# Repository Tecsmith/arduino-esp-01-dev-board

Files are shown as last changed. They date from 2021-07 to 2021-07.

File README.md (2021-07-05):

# Development board for ESP-01

| Board | URL |
|---|---|
| [ESP-01 Qwiic Development Board](https://tecsmith.github.io/arduino-esp-01-dev-board/) | [`c1k.it/esp1`](http://c1k.it/esp1) |

## Help, About, *etc.*

Refer to the [docs folder](docs/index.md).

<p align="center" style="color:#069">★</p>

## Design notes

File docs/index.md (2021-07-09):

# ESP-01 Qwiic Development Board

An ESP-01 Development Board with power, programming and Qwiic headers

GitHub repository at [Tecsmith/arduino-esp-01-dev-board](https://github.com/Tecsmith/arduino-esp-01-dev-board/)

----------

## Features & Specifications

- Host of ESP-01 (or ESP-01S) module.
- Powered from USB Micro-B connector
- Serial programing breakout pins (for use with SparkFun [FTDI 3.3V Breakout](https://www.sparkfun.com/products/9873))
- I<sup>2</sup>C breakout pins (SCL, SDA, 3V3, GND)
- Qwiic connector (works with SparkFun's [Qwiic Connect System](https://www.sparkfun.com/qwiic))
- Tactile GPIO0 momentary button (press to set ESP8266 into programming mode while booting)
- Tactile RESET momentary button (press to reboot ESP8266)
- Unlike common designs, this uses GPIO-0/GPIO-2 for I<sup>2</sup>C, leaving TX/RX (GPIO-1/GPIO-3) available for serial debug.

----------

## ESP-01 Pinout

| DevBrd | ESP |  Pin  |  Pin  | ESP | DevBrd |
|---:|---:|:-----:|:-----:|:---|:---|
| RXI / RXD | GPIO-3 / RX | **5** | **4** | VCC (3.3V)  | 3V3 |
| SCL / [*Prog/IO0*] | GPIO-0 | **6** | **3** | RST | [*Reset*] |
| SDA | GPIO-2 | **7** | **2** | CH_PD / EN  | EN / Enable |
| GND | GND | **8** | **1** | GPIO-1 / TX | TXO / TXD |

#### Sequence for placing EPS-01 in programing mode

1. Press and hold [*Reset*] button.
2. Press and hold [*Prog/IO0*] button.
3. Release [*Reset*] button
4. Wait 1 sec.
5. Pelease [*Prog/IO0*] - EPS-01 is now in "boot loader" mode.
6. *Perform upload code tasks*
7. Press and release [*Reset*] button to revert to run mode.

----------

## On Board Jumpers

### JP0 - On-board Enable
- Connected: Vcc *(3v3)* is bound to ESP-01 EN *(Enable)*
- Cut: EN is not connected, must bind EN pin to Vcc to Enable *(useful for adding on/off switch)*

### JP1 - I<sup>2</sup>C Pull Ups
- Connected _(default)_: 4.7KΩ pullups
- Cut both sides: No pullups

### JP2 - LED

As seen from the bottom:

- Tied to right (pin 2-3): LED ground to GND, always ON to show power state _(Default)_
- Tied to left (pin 1-2): LED ground to GPIO2 (as ESP-01 does) to show GPIO2 state when pulled low.
- Both cut: LED disabled

----------

## Manufacturing

* Schematic print: [esp-01-qwiic-devbrd-v1.2.pdf](esp-01-qwiic-devbrd-v1.2.pdf)
* Schematic source (in EAGLE): [Tecsmith/arduino-esp-01-dev-board/EAGLE/esp-01-qwiic-devbrd-v1.2.sch](https://github.com/Tecsmith/arduino-esp-01-dev-board/blob/main/EAGLE/esp-01-qwiic-devbrd-v1.2.sch)
* PCB design (in EAGLE): [Tecsmith/arduino-esp-01-dev-board/EAGLE/esp-01-qwiic-devbrd-v1.2.brd](https://github.com/Tecsmith/arduino-esp-01-dev-board/blob/main/EAGLE/esp-01-qwiic-devbrd-v1.2.brd)

| Top | Bottom |
|:---:|:---:|
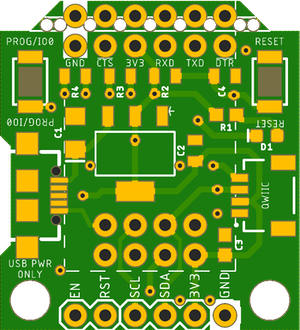
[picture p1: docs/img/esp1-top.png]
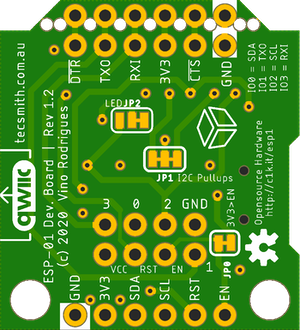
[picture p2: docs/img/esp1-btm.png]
|  |  |

<p align="center">2<sup>nd</sup> prototype built by JCLPCB</p>

----------

## Source Code

No source code is provided for the ESP-01, this is just a break out board that allows the ESP-01 to be used easily in a development environment and in some production cases.

I myself have been using [arendst/Tasmota](https://github.com/arendst/tasmota/) for MQTT integration, but the I2C on this board does ***not*** work on Tasmota base code.

Its important to note that most base code for the ESP8266 uses GPIOs 4 and 5 for I2C (as these are the manufacturers default), but the the ESP-01 board does not expose IOs 4 and 5.  This project uses GPIOs 0 and 2 for I2C (0 = SDA, 2 = SCL) and the Wire library needs to be initialised with the following code:

```cpp
// in header
#define SDA_PIN 0
#define SCL_PIN 2

// in setup()
Wire.begin(SDA_PIN, SCL_PIN);
```

----------
<p align="center" style="color:#069">&#9733;</p>

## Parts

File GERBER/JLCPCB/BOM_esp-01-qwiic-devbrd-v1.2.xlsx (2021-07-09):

Comment | Designator | Footprint | LCSC Part # (optional) | LCSC Type | Farnell Part #
TACTILE SWITCH | S1, S2 | SKRKAEE020 | C115357 | Extended | ✓
10uF Polar | C1 | CASE-A_3216 | C7171 | Basic | ✓
22uF | C2 | 805 | C45783 | Basic | ✓
0.1uF | C3 | 805 | C49678 | Basic | ✓
10uF | C4 | 805 | C15850 | Basic | ✓
1k Ohm | R1 | 805 | C17513 | Basic | ✓
4.7K Ohm | R2, R3, R4 | 805 | C17673 | Basic | ✓
BLUE | D1 | LED_0805 | C2293 | Basic | ✓
REG1117-3.3 | U2 | SOT-223 | C6186 | Basic | ✓

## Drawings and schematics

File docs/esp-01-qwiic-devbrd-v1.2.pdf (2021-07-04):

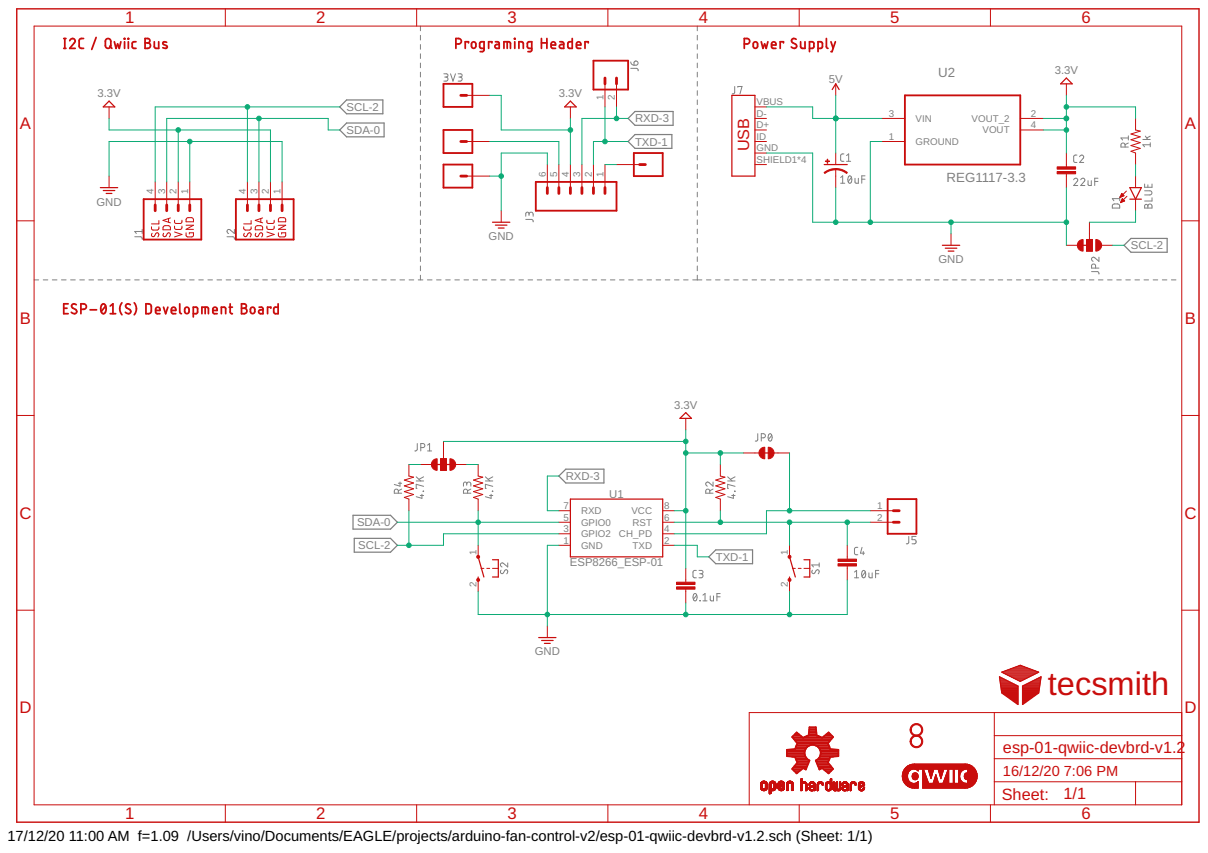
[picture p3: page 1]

17/12/20 11:00 AM f=1.09 /Users/vino/Documents/EAGLE/projects/arduino-fan-control-v2/esp-01-qwiic-devbrd-v1.2.sch (Sheet: 1/1)

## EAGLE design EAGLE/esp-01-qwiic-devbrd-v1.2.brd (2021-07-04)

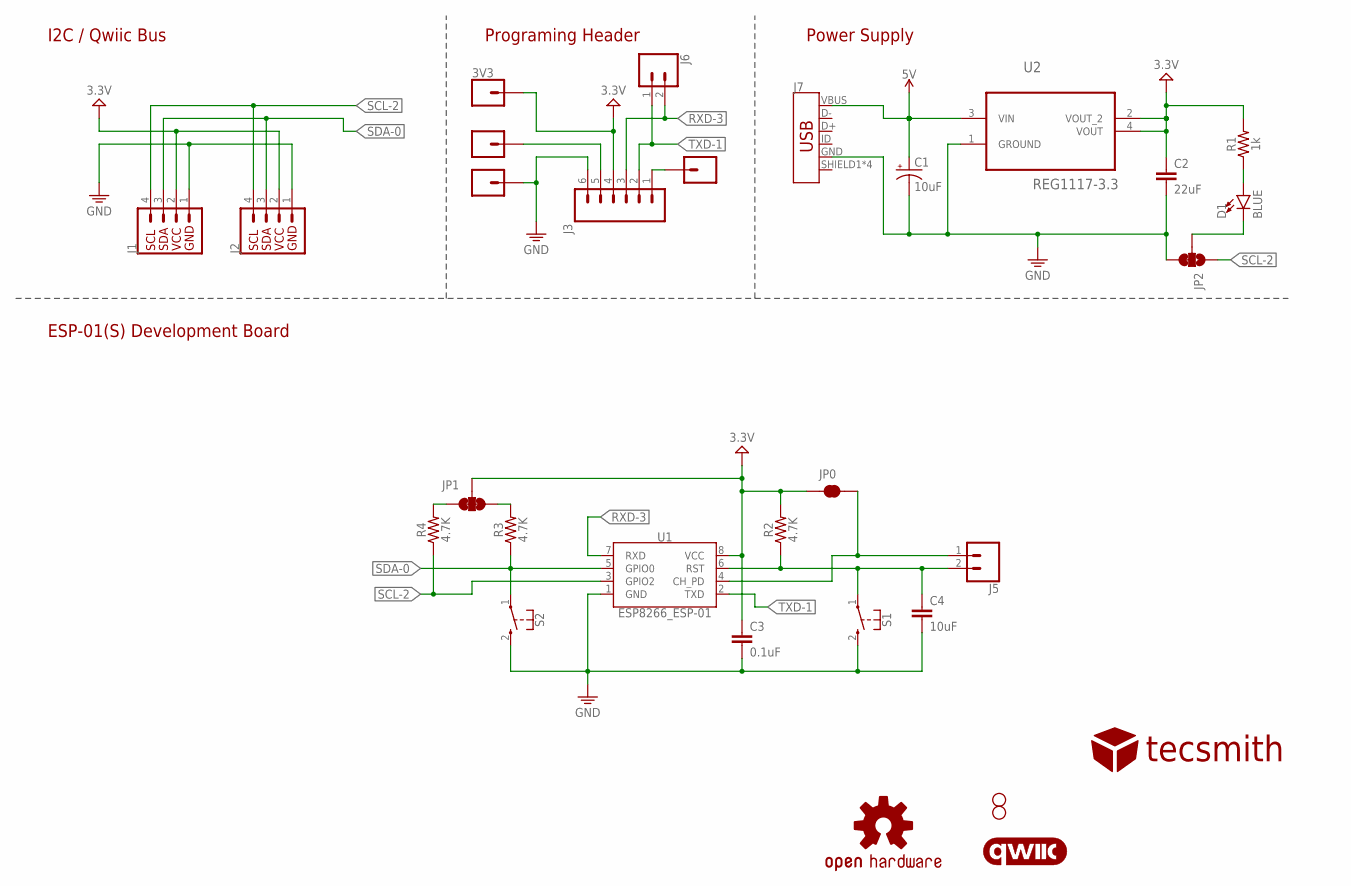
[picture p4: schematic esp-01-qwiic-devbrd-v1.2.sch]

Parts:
3V3: CONN_01PTH_NO_SILK_YES_STOP; 1X01_NO_SILK
C1: 10uF; EIA3216
C2: 22uF; 0805
C3: 0.1uF; 0603
C4: 10uF; 0805
D1: BLUE; LED-0603
H1, H2: STAND-OFF
J1: QWIIC_RIGHT_ANGLE; JST04_1MM_RA
J2: I2C_STANDARD; 1X04
J3: CONN_06NO_SILK_FEMALE_PTH; 1X06_NO_SILK
J4, J8, J9: CONN_01PTH_NO_SILK_YES_STOP; 1X01_NO_SILK
J5: CONN_02; 1X02
J6: CONN_021X02_NO_SILK; 1X02_NO_SILK
J7: USB_MICRO-B_FEMALE-SMT; USB-B-MICRO-SMD
JP0: JUMPER-SMT_2_NC_TRACE_SILK; SMT-JUMPER_2_NC_TRACE_SILK
JP1: JUMPER-SMT_3_2-NC_TRACE_SILK; SMT-JUMPER_3_2-NC_TRACE_SILK
JP2: JUMPER-SMT_3_1-NC_TRACE_SILK; SMT-JUMPER_3_1-NC_TRACE_SILK
LOGO1: OSHW-LOGOS; OSHW-LOGO-S
LOGO2: QWIIC_LOGO_6MM; QWIIC_6MM
R1: 1k; 0603
R2, R3, R4: 4.7K; 0805
S1, S2: MOMENTARY-SWITCH-SPST-1; SKRKAEE020
U1: ESP8266_ESP-01
U2: REG1117-3.3; SOT230P700X180-4N
U$1: TECSMITH-LOGO

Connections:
5V: C1.+, J7.VBUS, U2.3 (VIN)
CTS: J3.5, J8.1
DTR: J3.1, J9.1
EN: J5.1, JP0.2, U1.4 (CH_PD)
GND: C1.-, C2.2, C3.2, C4.2, J1.1, J2.1, J3.6, J4.1, J7.GND, JP2.3, S1.2 (3), S2.2 (3), U1.1 (GND), U2.1 (GROUND)
unnamed: D1.C, JP2.2
unnamed: D1.A, R1.1
unnamed: JP1.3, R4.2
unnamed: JP1.1, R3.2
RST: C4.1, J5.2, R2.1, S1.1, U1.6 (RST)
RXD-3: J3.3, J6.2, U1.7 (RXD)
SCL-2: J1.4, J2.4, JP2.1, R4.1, U1.3 (GPIO2)
SDA-0: J1.3, J2.3, R3.1, S2.1, U1.5 (GPIO0)
TXD-1: J3.2, J6.1, U1.2 (TXD)
VCC: 3V3.1, C2.1, C3.1, J1.2, J2.2, J3.4, JP0.1, JP1.2, R1.2, R2.2, U1.8 (VCC), U2.2 (VOUT_2), U2.4 (VOUT)

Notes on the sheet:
I2C / Qwiic Bus
Programing Header
Power Supply
ESP-01(S) Development Board

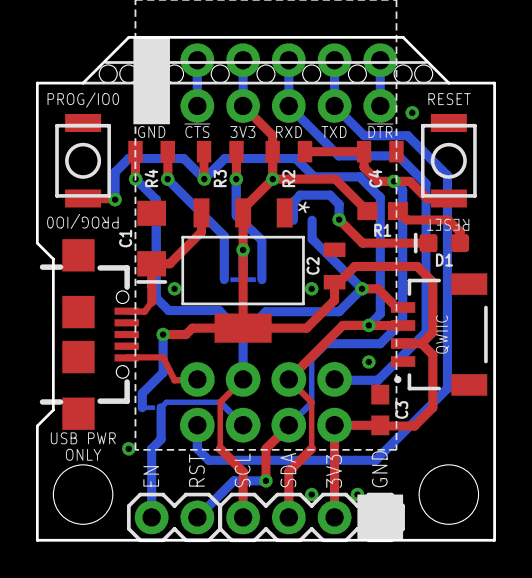
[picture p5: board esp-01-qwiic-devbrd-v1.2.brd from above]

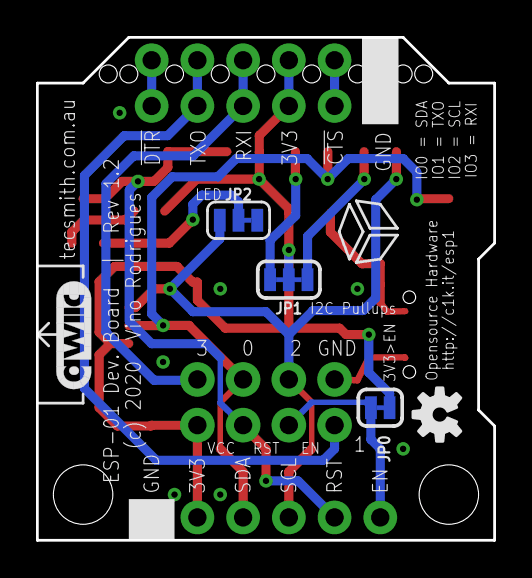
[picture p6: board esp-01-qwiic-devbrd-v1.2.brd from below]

Board: 2 copper layers, 25.4 x 27.9 mm, 31 parts (6 on the bottom side), 15 nets.

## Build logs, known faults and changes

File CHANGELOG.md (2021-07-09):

# Changelog

All notable changes to this project will be documented in this file.

The format is based on [Keep a Changelog](https://keepachangelog.com/en/1.0.0/),
and this project adheres to [Semantic Versioning](https://semver.org/spec/v2.0.0.html).

## [Unreleased]

*(No WIP)*

## [1.2.0] - 2020-12-16

### Changed

- Decided to use two momentary switches, one for RESET and another from PROGRAMING (added), but with limited space needed to modify board to use Alps Alpine SKRKAEE020 switches (not avail. from JLCPCB).
- Added C4 10μF capacitor to RESET pin for "debouncing" of the pushbutton.

## [1.1.0] - ?

*(Unreleased)*

## [1.0.0] - 2020-11-02

### Added

- Initial release

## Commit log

2021-07-04 moved from fan-control project
    [esp-01-qwiic-devbrd-v1.2.brd, esp-01-qwiic-devbrd-v1.2.sch]
2021-07-09 moving more files from the fan-control project
    [BOM_esp-01-qwiic-devbrd-v1.2.xlsx, PnP_esp-01-qwiic-devbrd-v1.2_front.xlsx, esp-01-qwiic-devbrd-v1.1.brd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]

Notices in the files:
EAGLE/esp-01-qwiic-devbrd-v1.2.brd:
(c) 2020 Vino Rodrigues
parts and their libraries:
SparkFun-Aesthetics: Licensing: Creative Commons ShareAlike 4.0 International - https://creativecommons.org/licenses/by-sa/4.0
